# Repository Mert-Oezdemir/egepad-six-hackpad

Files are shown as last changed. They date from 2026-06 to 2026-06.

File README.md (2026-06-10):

# EgePad Six Hackpad

Project owner: **Ege Özdemir**

EgePad Six is a compact Hackpad macropad design for the Hack Club Hackpad mission. It uses a 2x3 MX switch matrix, one EC11 rotary encoder, and a Seeed XIAO RP2040 running KMK firmware.

GitHub repository: https://github.com/Mert-Oezdemir/egepad-six-hackpad

This repository follows the Hackpad submission structure described in the official guide: PCB design files, CAD/STEP case files, firmware, and production outputs are kept in separate folders.

Stardance helper: open [START_STARDANCE.html](START_STARDANCE.html) locally for project links and one-click copy fields.

Official reference:
- Hackpad guide: https://hackpad.hackclub.com/guide
- Stardance Hackpad mission guide: https://stardance.hackclub.com/missions/hackpad/guide

## Design Summary

| Item | Value |
| --- | --- |
| Name | EgePad Six |
| Owner | Ege Özdemir |
| MCU | Seeed XIAO RP2040 |
| Inputs | 6 MX switches + 1 EC11 rotary encoder |
| Firmware | KMK / CircuitPython |
| PCB size target | 92mm x 60mm, 2-layer |
| Case size target | 112mm x 80mm x 18mm |
| Switch spacing | 19.05mm center-to-center |
| Mounting | M3 screws + M3 heatset inserts |

## Render / Screenshots

### Macropad Design Render

Macropad render

### Schematic Preview

Schematic preview

### PCB Layout Preview

PCB layout preview

### Case 3D Preview

Case preview

## Bill Of Materials

| Ref | Component | Qty | Source |
| --- | --- | ---: | --- |
| U1 | Seeed XIAO RP2040 | 1 | Hackpad kit |
| SW1-SW6 | MX-style mechanical switch | 6 | Hackpad kit |
| D1-D6 | 1N4148 through-hole diode | 6 | Hackpad kit |
| ENC1 | EC11 rotary encoder, 20mm D-shaft | 1 | Hackpad kit |
| KC1-KC6 | Blank DSA keycap | 6 | Hackpad kit |
| H1-H6 | M3 x 5 x 4mm heatset insert | 6 | Hackpad kit |
| S1-S6 | M3 x 16mm screw | 6 | Hackpad kit |
| PCB | 2-layer PCB, max 92mm x 60mm | 1 | JLCPCB grant |
| CASE | 3D-printed top and bottom case | 1 set | Printing Legion |

CSV version: [BOM.csv](BOM.csv)

## Wiring Plan

The key matrix uses two rows and three columns:

| Matrix | Column 0 | Column 1 | Column 2 |
| --- | --- | --- | --- |
| Row 0 | SW1 | SW2 | SW3 |
| Row 1 | SW4 | SW5 | SW6 |

XIAO pin plan:

| Function | XIAO Pin |
| --- | --- |
| Row 0 | D0 |
| Row 1 | D1 |
| Col 0 | D2 |
| Col 1 | D3 |
| Col 2 | D4 |
| Encoder A | D8 |
| Encoder B | D9 |
| Encoder button | D10 |

Diode orientation target: `COL2ROW`, with diode stripe toward the row wire.

## Folder Structure

```text
.
├── README.md
├── CAD/
│   ├── assembled-model.STEP
│   ├── Top.STEP
│   ├── Bottom.STEP
│   └── README.md
├── PCB/
│   ├── egepad.kicad_pro
│   ├── egepad.kicad_sch
│   ├── egepad.kicad_pcb
│   └── README.md
├── Firmware/
│   └── main.py
└── production/
    ├── gerbers.zip
    ├── Top.STEP
    ├── Bottom.STEP
    └── main.py
```

## Pre-Submission Status

See [RELEASE_STATUS.md](RELEASE_STATUS.md).

Requirement mapping:

- [Hackpad requirements map](HACKPAD_REQUIREMENTS_MAP.md)
- [Stardance submission handoff](STARDANCE_SUBMISSION.md)
- [Stardance launch helper](START_STARDANCE.html)
- [Mechanical dimensions](CAD/MECHANICAL_DIMENSIONS.md)
- [Firmware notes](Firmware/README.md)

Important note: this environment does not have KiCad CLI or a CAD kernel installed, so the PCB DRC, real Gerber export, and STEP geometry have not been tool-verified here. The repo is prepared as a complete Hackpad submission package scaffold and should be opened in KiCad/Fusion 360 for final manufacturability checks before submitting.

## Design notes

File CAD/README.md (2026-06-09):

# CAD Notes

Owner: Ege Özdemir

Target case:

- Top plate: 112mm x 80mm x 3mm
- Bottom shell: 112mm x 80mm x 13mm
- Final assembled height target: 18mm before keycaps/encoder knob
- PCB internal clearance target: 92.8mm x 60.8mm, giving 0.4mm per side tolerance around a 92mm x 60mm PCB
- MX switch cutouts: 14mm x 14mm
- Heatset insert holes: 4.7mm diameter, 4mm deep
- Screw pass-through holes: 3.4mm diameter
- USB-C side cutout: 12mm x 8mm on the right edge near the XIAO

The included STEP files are draft/concept STEP files generated as submission placeholders in an environment without a CAD kernel. Open the design in Fusion 360 or another CAD tool and export final STEP geometry before final Hackpad submission.

Source files:

- `egepad_case.scad`: measured case source with switch cutouts, encoder cutout, screw holes, insert pockets, PCB pocket, and USB-C cutout.
- `MECHANICAL_DIMENSIONS.md`: dimension table for manual CAD review.

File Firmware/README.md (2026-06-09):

# Firmware Notes

Owner: Ege Özdemir

Firmware target: KMK on CircuitPython for Seeed XIAO RP2040.

## Files

- `main.py`: primary firmware copied to the board root.

## Matrix

| Row | Pin |
| --- | --- |
| Row 0 | D0 |
| Row 1 | D1 |

| Column | Pin |
| --- | --- |
| Col 0 | D2 |
| Col 1 | D3 |
| Col 2 | D4 |

Diode orientation: `COL2ROW`.

## Encoder

| Encoder function | Pin |
| --- | --- |
| A | D8 |
| B | D9 |
| Switch | D10 |

## Default Keymap

| Position | Key |
| --- | --- |
| Top left | Esc |
| Top middle | Ctrl+C |
| Top right | Ctrl+V |
| Bottom left | Ctrl+Z |
| Bottom middle | Ctrl+S |
| Bottom right | Enter |
| Encoder left | Volume down |
| Encoder right | Volume up |
| Encoder press | Mute |

## Manual Test Plan

1. Install CircuitPython on the XIAO RP2040.
2. Install KMK on the board.
3. Copy `Firmware/main.py` to the board root.
4. Open a keyboard tester.
5. Press all six switches.
6. Rotate encoder left and right.
7. Press encoder switch.

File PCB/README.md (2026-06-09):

# PCB Notes

Owner: Ege Özdemir

Design target:

- Board: 92mm x 60mm, 2 layers.
- MCU: Seeed XIAO RP2040, bottom side, USB-C toward right-side case cutout.
- Matrix: 2 rows x 3 columns, six 1N4148 diodes, COL2ROW.
- Encoder: one EC11 on the right side.

Pin map:

| Net | XIAO pin |
| --- | --- |
| ROW0 | D0 |
| ROW1 | D1 |
| COL0 | D2 |
| COL1 | D3 |
| COL2 | D4 |
| ENCA | D8 |
| ENCB | D9 |
| ENCSW | D10 |

The KiCad files are hand-authored draft files because KiCad CLI is not installed in this environment. Open in KiCad, assign the Hackpad care package XIAO/MX footprints, run ERC/DRC, and export real Gerbers before final submission.

Supporting contract files:

- `pinout.csv`: XIAO pin and firmware signal mapping.
- `matrix-map.csv`: physical key locations, matrix positions, and default keymap.

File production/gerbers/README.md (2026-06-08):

# Draft Gerber Package Notes

These files are hand-authored placeholders so the submission package has the expected `production/gerbers.zip` path.

Before final Hackpad submission:

1. Open `PCB/egepad.kicad_pro` in KiCad.
2. Run ERC/DRC.
3. Export real Gerbers and drill files from KiCad.
4. Replace this folder and `production/gerbers.zip`.

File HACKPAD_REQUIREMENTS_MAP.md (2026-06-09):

# Hackpad Requirements Map

Project: EgePad Six Hackpad

Owner: Ege Özdemir

Repository: https://github.com/Mert-Oezdemir/egepad-six-hackpad

## Requirement Coverage

| Hackpad expectation | Repo evidence | Status |
| --- | --- | --- |
| Public GitHub repository | `README.md`, pushed `main` branch | Done |
| Project owner recorded | `README.md`, `project.json`, `SUBMISSION.md` | Done |
| Original hackpad concept | EgePad Six 2x3 layout + encoder design | Done as concept |
| README with overview | `README.md` | Done |
| Visual previews | `assets/*.svg` referenced in `README.md` | Done as design previews |
| BOM | `BOM.csv` and README BOM table | Done |
| PCB files | `PCB/egepad.kicad_pro`, `PCB/egepad.kicad_sch`, `PCB/egepad.kicad_pcb` | Draft present |
| Firmware | `Firmware/main.py` and `production/main.py` | Draft present |
| CAD / case files | `CAD/*.STEP`, `CAD/egepad_case.scad`, `CAD/MECHANICAL_DIMENSIONS.md` | Draft present with measured source |
| Production files | `production/gerbers.zip`, `production/*.STEP`, `production/main.py` | Draft present |
| Stardance handoff | `STARDANCE_SUBMISSION.md`, `STARDANCE_SUBMIT_TEXT.md` | Done |

## Honest Gate Split

Ready for Stardance project logging: **YES**

Ready for manufacturing without more work: **NO**

The repo is ready to show the project, intent, structure, and build plan. It is not yet a verified manufacturing package because this environment does not include KiCad CLI, KiCad GUI, Fusion 360, FreeCAD, OpenSCAD, or KMK hardware test access.

## Manual Final Validation Required

1. Open `PCB/egepad.kicad_pro` in KiCad.
2. Replace draft/custom footprints with Hackpad care package footprints where needed.
3. Run ERC.
4. Run DRC.
5. Export real Gerbers and replace `production/gerbers.zip`.
6. Open or rebuild the case in CAD.
7. Use `CAD/egepad_case.scad` and `CAD/MECHANICAL_DIMENSIONS.md` as source references.
8. Export real `Top.STEP`, `Bottom.STEP`, and `assembled-model.STEP`.
9. Install CircuitPython + KMK on a XIAO RP2040.
10. Copy `Firmware/main.py`.
11. Test all six keys and encoder directions/button.

## One-Command Local Checks

Scaffold check:

```powershell
powershell -ExecutionPolicy Bypass -File scripts\check-submission.ps1
```

Final readiness check:

```powershell
powershell -ExecutionPolicy Bypass -File scripts\check-final-readiness.ps1
```

Clean source package:

```powershell
powershell -ExecutionPolicy Bypass -File scripts\package-source.ps1
```

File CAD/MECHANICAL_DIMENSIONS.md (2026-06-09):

# EgePad Six Mechanical Dimensions

Owner: Ege Özdemir

All dimensions are in millimeters.

## Case

| Dimension | Value |
| --- | ---: |
| Outer width | 112 |
| Outer height | 80 |
| Bottom shell height | 13 |
| Top plate thickness | 3 |
| Corner radius | 8 |
| Wall thickness | 3 |
| Floor thickness | 2 |
| Approx assembled case height | 16.2 |

## PCB Envelope

| Dimension | Value |
| --- | ---: |
| PCB width | 92 |
| PCB height | 60 |
| PCB pocket width | 92.8 |
| PCB pocket height | 60.8 |
| Clearance per side | 0.4 |

## Switches And Encoder

| Feature | Value |
| --- | ---: |
| MX cutout | 14 x 14 |
| Switch pitch | 19.05 |
| Switch layout | 2 rows x 3 columns |
| Encoder cutout diameter | 14 |
| Encoder center | X 88, Y 28 |

## Fasteners

| Feature | Value |
| --- | ---: |
| Screw pass-through | 3.4 diameter |
| Heatset insert pocket | 4.7 diameter |
| Heatset insert depth | 4 |
| Fastener count | 6 |

## Cutouts

| Feature | Value |
| --- | ---: |
| USB-C side cutout | 12 x 8 |
| USB-C cutout side | right edge |

Source CAD file: `CAD/egepad_case.scad`.

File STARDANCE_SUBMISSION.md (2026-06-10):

# Stardance Submission Handoff

Project: EgePad Six Hackpad

Owner: Ege Özdemir

GitHub repository:

https://github.com/Mert-Oezdemir/egepad-six-hackpad

Hackpad guide:

https://hackpad.hackclub.com/guide

## What To Submit On Stardance

Use the GitHub repository link above as the project link.

Stardance requires sign-in before creating a project. Open `Open-Stardance-Hackpad-Mission.url`, sign in if prompted, then create the project from the Hackpad mission page.

For a more guided local flow, open `START_STARDANCE.html`. It has direct links to Stardance/GitHub and one-click copy buttons for the project title, owner, repo link, and description.

Suggested short description:

```text
EgePad Six is a compact Hackpad macropad by Ege Özdemir with a 2x3 MX switch matrix, an EC11 rotary encoder, XIAO RP2040 controller, KMK firmware, PCB files, CAD files, BOM, and production package structure.
```

## Current Evidence

- GitHub repository exists and `main` has been pushed.
- Required Hackpad folders are present: `CAD/`, `PCB/`, `Firmware/`, and `production/`.
- README includes project owner, BOM, wiring plan, and visual previews.
- `HACKPAD_REQUIREMENTS_MAP.md` maps every expected submission item to repo evidence.
- Local submission scaffold check passes with `scripts/check-submission.ps1`.
- Clean source zip can be generated with `scripts/package-source.ps1`.

## Honest Status

Ready for Stardance project logging / repo link submission: **YES**

Ready for final PCB manufacturing without manual review: **NO**

Final manual checks still required:

- KiCad ERC/DRC.
- KiCad-generated Gerbers replacing the draft `production/gerbers.zip`.
- CAD-kernel-generated STEP exports replacing the draft STEP placeholders.
- Firmware test on XIAO RP2040 with KMK installed.

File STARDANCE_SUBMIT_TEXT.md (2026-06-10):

# Stardance Submit Text

Use this when creating the Stardance project.

Local helper: open `START_STARDANCE.html` for direct links and one-click copy buttons.

## Project Title

EgePad Six Hackpad

## Project Owner

Ege Özdemir

## GitHub Link

https://github.com/Mert-Oezdemir/egepad-six-hackpad

## Short Description

EgePad Six is a compact Hackpad macropad project by Ege Özdemir. It has a 2x3 MX switch matrix, one EC11 rotary encoder, a Seeed XIAO RP2040 controller, KMK firmware, PCB draft files, CAD/STEP draft files, BOM, visual previews, and the production folder structure requested by the Hackpad guide.

## Longer Build Log / Notes

I created the repository structure required for the Hackpad mission:

- `CAD/` for the case files and STEP drafts.
- `PCB/` for KiCad project, schematic, and PCB draft files.
- `Firmware/` for KMK firmware.
- `production/` for Gerber zip, STEP copies, and firmware copy.
- `README.md` for visuals, wiring plan, BOM, and project notes.

The design target is a 92mm x 60mm PCB with a 112mm x 80mm 3D-printable sandwich case. The input layout is six MX switches plus one rotary encoder.

## Honest Status

Ready to log on Stardance with the GitHub repo link: yes.

Still needs manual final validation before manufacturing:

- KiCad ERC/DRC.
- KiCad-generated Gerbers.
- CAD-tool-generated STEP files.
- Firmware test on a XIAO RP2040 with KMK installed.

## Links To Open

- GitHub repo: https://github.com/Mert-Oezdemir/egepad-six-hackpad
- Hackpad mission: https://stardance.hackclub.com/missions/hackpad
- Hackpad guide: https://hackpad.hackclub.com/guide

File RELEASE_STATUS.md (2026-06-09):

# EgePad Six Release Status

Owner: Ege Özdemir

Date: 2026-06-08

## Current Gate

Status: **NO-GO for final Hackpad submission until manual KiCad/CAD validation is completed.**

GitHub repository: https://github.com/Mert-Oezdemir/egepad-six-hackpad

## Completed In This Workspace

- Repository folder structure matches the Hackpad guide.
- README contains owner, design summary, visuals, and BOM.
- Firmware `main.py` is included for KMK/CircuitPython.
- PCB KiCad project/schematic/PCB draft files are included.
- CAD and production STEP draft files are included.
- Hand-authored Gerber draft files are staged for packaging into `production/gerbers.zip`.
- Local git repository was initialized and the project was committed.
- A click helper was added: `Create-GitHub-Repo.url` opens GitHub repo creation with the suggested project name.
- A push helper was added: `PUSH_AFTER_GITHUB_REPO_CREATED.cmd` prompts for the created repo URL and pushes `main`.
- A clean source package helper was added: `scripts/package-source.ps1`.
- GitHub push to `origin/main` has completed.
- Measured CAD source and dimension notes were added under `CAD/`.
- Pinout, matrix map, and firmware notes were added.

## Not Verified Here

- KiCad CLI is not installed, so DRC/ERC was not run.
- KiCad CLI is not installed, so production Gerbers were not exported from KiCad.
- FreeCAD/OpenSCAD/Fusion 360 is not installed, so STEP geometry was not generated from a real CAD kernel here.
- KMK is not installed locally, so firmware import/runtime validation was not run.
- GitHub CLI (`gh`) is not installed, so future GitHub automation should use plain `git` or the browser helpers unless `gh` is installed.

## Final Manual Checks

1. Open `PCB/egepad.kicad_pro` in KiCad.
2. Reassign symbols/footprints using the Hackpad care package libraries.
3. Run ERC and DRC.
4. Export real Gerbers and replace `production/gerbers.zip`.
5. Open/import the case design in Fusion 360 or another CAD tool.
6. Export final `Top.STEP`, `Bottom.STEP`, and `assembled-model.STEP`.
7. Copy `Firmware/main.py` to a CircuitPython XIAO RP2040 with KMK installed and confirm the matrix works.
8. Update this file to GO only after the above checks pass.

## Local Check Commands

Scaffold:

```powershell
powershell -ExecutionPolicy Bypass -File scripts\check-submission.ps1
```

Final readiness:

```powershell
powershell -ExecutionPolicy Bypass -File scripts\check-final-readiness.ps1
```

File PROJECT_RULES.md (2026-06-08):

# EgePad Six Project Rules

Owner: Ege Özdemir

## Working Discipline

- Keep this repo focused on the Hackpad submission package.
- Do not copy files or implementation details from MAIAS or KilitMesaj; only reuse their release discipline.
- Keep proof and uncertainty visible: build/check status belongs in `RELEASE_STATUS.md`.
- Do not mark the project production-ready until KiCad DRC, Gerber export, CAD export, and firmware validation are complete.
- Keep hardware constraints explicit: PCB under 100mm x 100mm, case under 200mm x 200mm x 100mm, kit parts only unless noted.

## Submission Gates

- README includes design render, schematic preview, PCB preview, case preview, and BOM.
- PCB design files exist under `PCB/`.
- CAD/STEP files exist under `CAD/` and `production/`.
- Firmware exists under `Firmware/` and `production/`.
- Gerber archive exists under `production/`.
- Final manual KiCad/Fusion review is still required before Hackpad submission.

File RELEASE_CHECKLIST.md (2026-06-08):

# EgePad Six Release Checklist

Owner: Ege Özdemir

## Hackpad Structure

- [x] `README.md`
- [x] `CAD/assembled-model.STEP`
- [x] `PCB/egepad.kicad_pro`
- [x] `PCB/egepad.kicad_sch`
- [x] `PCB/egepad.kicad_pcb`
- [x] `Firmware/main.py`
- [x] `production/gerbers.zip`
- [x] `production/Top.STEP`
- [x] `production/Bottom.STEP`
- [x] `production/main.py`

## Hackpad Constraints

- [x] PCB target is under 100mm x 100mm.
- [x] Case target is under 200mm x 200mm x 100mm.
- [x] Case is intended to be fully 3D-printable.
- [x] Uses kit parts only.
- [x] USB-C cutout is planned on the XIAO side.
- [x] Heatset insert target holes: 4.7mm diameter.
- [x] Screw pass-through target holes: 3.4mm diameter.
- [x] Mating surface tolerance target: 0.2mm.

## Manual Validation Still Required

- [ ] KiCad ERC passes.
- [ ] KiCad DRC passes.
- [ ] Real Gerbers exported from KiCad.
- [ ] JLCPCB preview checked.
- [ ] Final CAD exported from a CAD tool.
- [ ] Case 3D print fit checked.
- [ ] KMK firmware tested on XIAO RP2040.
- [ ] README screenshots replaced with final KiCad/CAD screenshots if needed.

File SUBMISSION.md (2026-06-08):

# Hackpad Submission Metadata

Project: EgePad Six Hackpad

Project owner: Ege Özdemir

Prepared for: Hack Club Hackpad mission

Guide: https://hackpad.hackclub.com/guide

## Submission Notes

- The repo structure is prepared for Hackpad review.
- Manual KiCad/CAD validation is still required before final submission.
- Do not submit as GO until `RELEASE_STATUS.md` is updated after manual validation.

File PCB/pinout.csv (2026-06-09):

Signal | XIAO Pin | Firmware Pin | Function
ROW0 | D0 | board.D0 | Matrix row 0
ROW1 | D1 | board.D1 | Matrix row 1
COL0 | D2 | board.D2 | Matrix column 0
COL1 | D3 | board.D3 | Matrix column 1
COL2 | D4 | board.D4 | Matrix column 2
ENCA | D8 | board.D8 | Encoder A
ENCB | D9 | board.D9 | Encoder B
ENCSW | D10 | board.D10 | Encoder push switch
GND | GND | board.GND | Ground

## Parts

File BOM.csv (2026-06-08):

Ref | Component | Qty | Source | Notes
U1 | Seeed XIAO RP2040 | 1 | Hackpad kit | Through-hole mounted on bottom side
SW1-SW6 | MX-style mechanical switch | 6 | Hackpad kit | 2x3 layout at 19.05mm spacing
D1-D6 | 1N4148 through-hole diode | 6 | Hackpad kit | Stripe toward row wire
ENC1 | EC11 rotary encoder 20mm D-shaft | 1 | Hackpad kit | Right side volume/scroll encoder
KC1-KC6 | Blank DSA keycap | 6 | Hackpad kit | One per switch
H1-H6 | M3 x 5 x 4mm heatset insert | 6 | Hackpad kit | Bottom case
S1-S6 | M3 x 16mm screw | 6 | Hackpad kit | Top plate pass-through
PCB | 2-layer PCB | 1 | JLCPCB grant | 92mm x 60mm target
CASE | 3D-printed top and bottom case | 1 set | Printing Legion | 112mm x 80mm x 18mm target

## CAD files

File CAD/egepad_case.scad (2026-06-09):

// EgePad Six Hackpad case source
// Owner: Ege Ozdemir
// Units: millimeters
//
// Export targets:
// - Top.STEP / Top.stl from top_plate()
// - Bottom.STEP / Bottom.stl from bottom_shell()
// - assembled-model.STEP / assembled-model.stl from assembled_preview()
//
// This file is the measured CAD source for the sandwich case concept.

$fn = 48;

case_w = 112;
case_h = 80;
corner_r = 8;

top_t = 3;
bottom_t = 13;
wall = 3;
floor_t = 2;

pcb_w = 92;
pcb_h = 60;
pcb_clearance = 0.4;

switch_cutout = 14;
switch_pitch = 19.05;
switch_origin_x = 28;
switch_origin_y = 24;

encoder_x = 88;
encoder_y = 28;
encoder_cutout_d = 14;

screw_d = 3.4;
insert_d = 4.7;
insert_depth = 4;

usb_cutout_w = 12;
usb_cutout_h = 8;

mounts = [
  [10, 10],
  [case_w - 10, 10],
  [10, case_h - 10],
  [case_w - 10, case_h - 10],
  [case_w / 2, 10],
  [case_w / 2, case_h - 10]
];

module rounded_box(w, h, z, r) {
  linear_extrude(height = z)
    hull() {
      translate([r, r]) circle(r);
      translate([w - r, r]) circle(r);
      translate([r, h - r]) circle(r);
      translate([w - r, h - r]) circle(r);
    }
}

module switch_grid_cutouts() {
  for (row = [0:1]) {
    for (col = [0:2]) {
      translate([
        switch_origin_x + col * switch_pitch,
        switch_origin_y + row * switch_pitch,
        -0.5
      ])
        cube([switch_cutout, switch_cutout, top_t + 1], center = true);
    }
  }
}

module screw_cutouts(d, z) {
  for (p = mounts) {
    translate([p[0], p[1], -0.5])
      cylinder(h = z + 1, d = d);
  }
}

module top_plate() {
  difference() {
    rounded_box(case_w, case_h, top_t, corner_r);
    switch_grid_cutouts();
    translate([encoder_x, encoder_y, -0.5])
      cylinder(h = top_t + 1, d = encoder_cutout_d);
    screw_cutouts(screw_d, top_t);
  }
}

module bottom_shell() {
  difference() {
    rounded_box(case_w, case_h, bottom_t, corner_r);

    translate([
      (case_w - (pcb_w + pcb_clearance * 2)) / 2,
      (case_h - (pcb_h + pcb_clearance * 2)) / 2,
      floor_t
    ])
      cube([pcb_w + pcb_clearance * 2, pcb_h + pcb_clearance * 2, bottom_t]);

    // XIAO USB-C cutout on right wall.
    translate([case_w - wall - 0.2, 48, 4])
      cube([wall + 1, usb_cutout_w, usb_cutout_h]);

    for (p = mounts) {
      translate([p[0], p[1], bottom_t - insert_depth])
        cylinder(h = insert_depth + 1, d = insert_d);
    }
  }
}

module assembled_preview() {
  color("#94a3b8") bottom_shell();
  translate([0, 0, bottom_t + 0.2])
    color("#e2e8f0") top_plate();
}

assembled_preview();

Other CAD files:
CAD/assembled-model.STEP
production/Top.STEP
CAD/Top.STEP
production/Bottom.STEP
CAD/Bottom.STEP

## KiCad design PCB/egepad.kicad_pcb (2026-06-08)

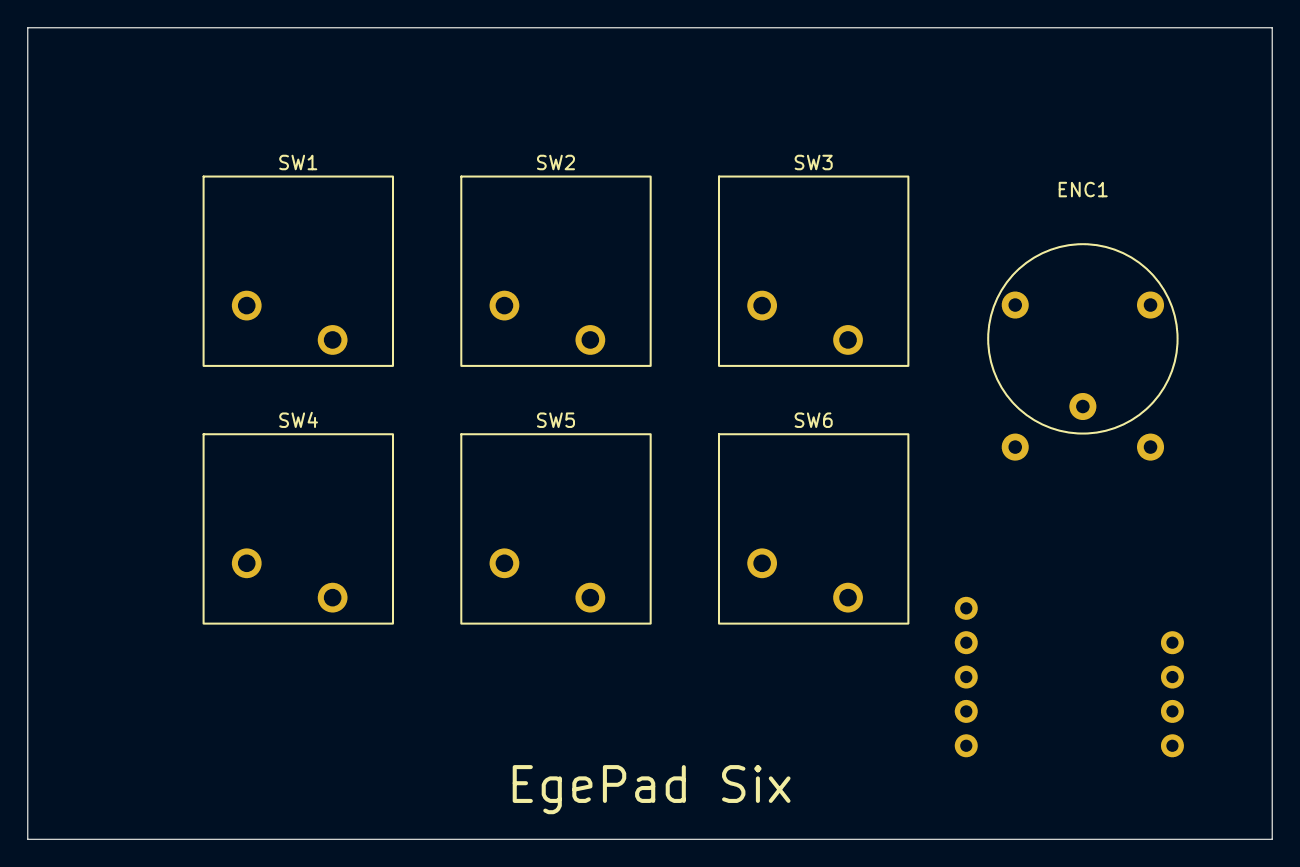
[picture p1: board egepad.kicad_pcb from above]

Board: 2 copper layers, 92.0 x 60.0 mm, 8 parts (1 on the bottom side), 9 nets, no tracks yet.

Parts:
ENC1: EC11; EC11_DRAFT
SW1, SW2, SW3, SW4, SW5, SW6: MX; MX_1U_DRAFT
U1: XIAO_RP2040; XIAO_RP2040_DRAFT

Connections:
COL0: SW1.1, SW4.1, U1.D2
COL1: SW2.1, SW5.1, U1.D3
COL2: SW3.1, SW6.1, U1.D4
ENCA: ENC1.A, U1.D8
ENCB: ENC1.B, U1.D9
ENCSW: ENC1.SW1, U1.D10
GND: ENC1.C, ENC1.SW2, U1.GND
ROW0: SW1.2, SW2.2, SW3.2, U1.D0
ROW1: SW4.2, SW5.2, SW6.2, U1.D1

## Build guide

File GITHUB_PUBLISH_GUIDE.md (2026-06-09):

# GitHub Publish Helper

Project: EgePad Six Hackpad

Owner: Ege Özdemir

Repository:

https://github.com/Mert-Oezdemir/egepad-six-hackpad

One-click helpers:

- `Open-GitHub-Repo.url`
- `Open-Stardance-Hackpad-Mission.url`
- `Open-Stardance-Projects.url`

## One-Click Repo Creation Link

Double-click:

```text
Create-GitHub-Repo.url
```

This opens GitHub's new repository page with the suggested repo name:

```text
egepad-six-hackpad
```

GitHub still requires you to confirm the repository creation in the browser. That part cannot be safely bypassed by a local file.

## Push After Repo Exists

After creating the repo, double-click:

```text
PUSH_AFTER_GITHUB_REPO_CREATED.cmd
```

Paste the new GitHub HTTPS repo URL when prompted. The helper will:

1. Add or update `origin`.
2. Run `git push -u origin main`.

## Shareable Source Package

If GitHub push is blocked, create a clean source zip:

```powershell
powershell -ExecutionPolicy Bypass -File scripts\package-source.ps1
```

Output:

```text
output/egepad-six-hackpad-source.zip
```

The package excludes `.git`, `.env*`, logs, cache folders, and generated junk.

## Current Known State

- Local commit exists.
- Push to `origin/main` has completed.
- Clean source package can be generated with `scripts/package-source.ps1`.
- Hardware/CAD manufacturing validation is still not complete; see `RELEASE_STATUS.md`.

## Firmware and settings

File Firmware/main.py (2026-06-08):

import board

from kmk.kmk_keyboard import KMKKeyboard
from kmk.keys import KC
from kmk.modules.encoder import EncoderHandler
from kmk.scanners import DiodeOrientation


keyboard = KMKKeyboard()

# EgePad Six: 2 rows x 3 columns. Match these pins to the KiCad matrix.
keyboard.row_pins = (board.D0, board.D1)
keyboard.col_pins = (board.D2, board.D3, board.D4)
keyboard.diode_orientation = DiodeOrientation.COL2ROW

encoder_handler = EncoderHandler()
keyboard.modules.append(encoder_handler)

encoder_handler.pins = ((board.D8, board.D9, board.D10, False),)
encoder_handler.map = [
    ((KC.VOLD, KC.VOLU, KC.MUTE),),
]

keyboard.keymap = [
    [
        KC.ESC,
        KC.LCTL(KC.C),
        KC.LCTL(KC.V),
        KC.LCTL(KC.Z),
        KC.LCTL(KC.S),
        KC.ENT,
    ],
]


if __name__ == "__main__":
    keyboard.go()

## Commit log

2026-06-08 Create EgePad Six hackpad project
    [BOM.csv, Bottom.STEP, Top.STEP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]
2026-06-09 Add measured CAD and hardware contracts
    [egepad_case.scad, matrix-map.csv, pinout.csv]
